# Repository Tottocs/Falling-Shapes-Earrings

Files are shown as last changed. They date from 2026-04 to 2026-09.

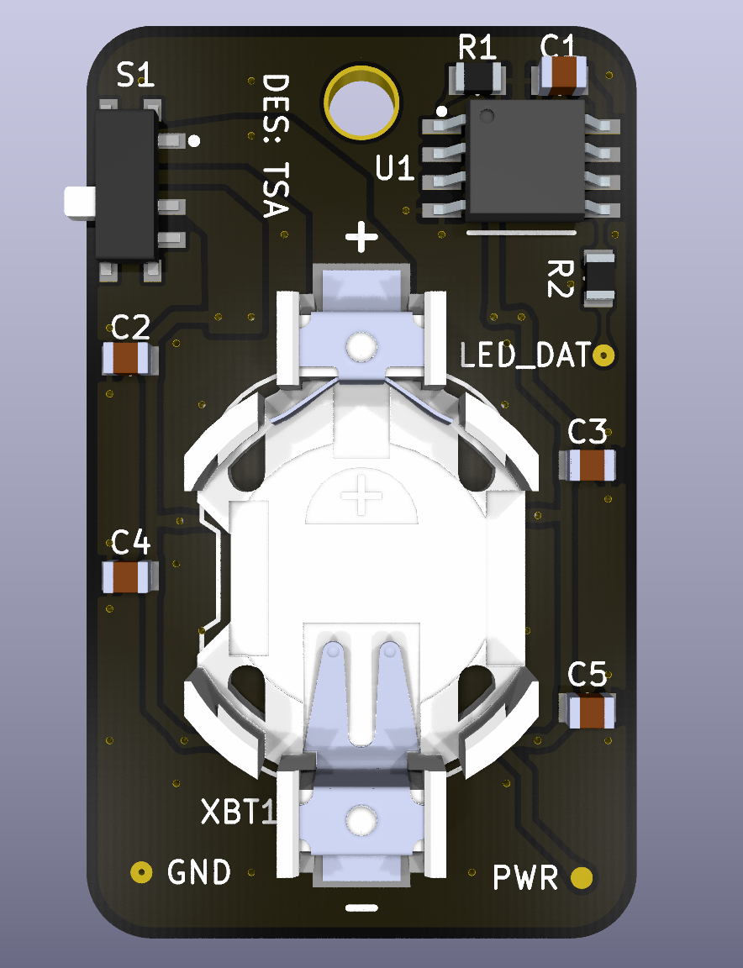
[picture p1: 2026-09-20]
pictures/renders/back.png

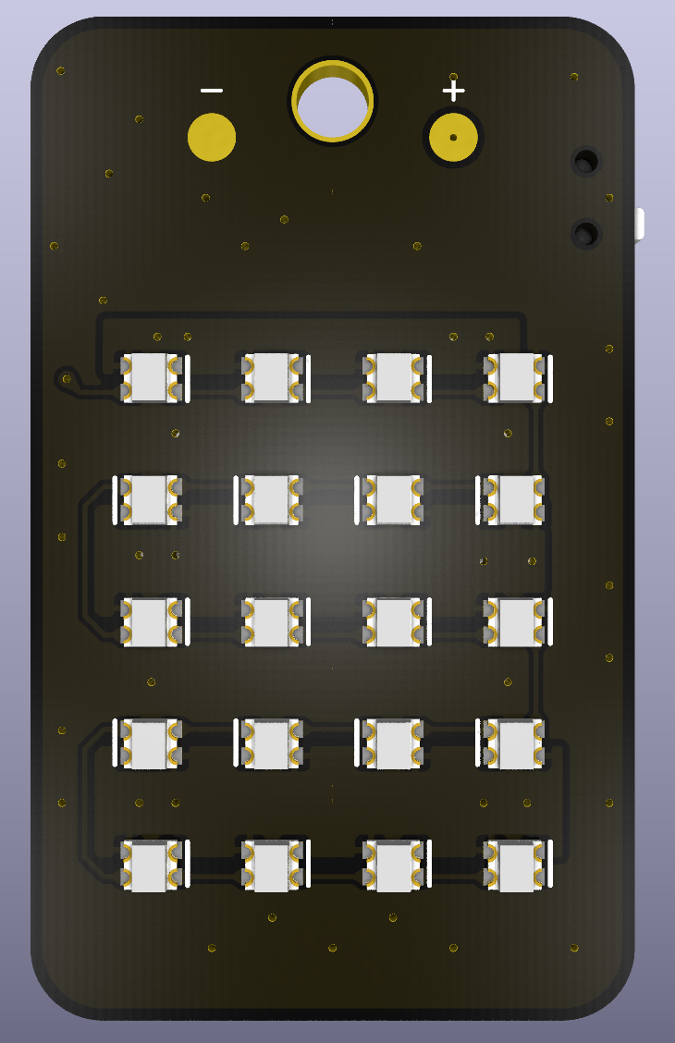
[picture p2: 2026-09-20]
pictures/renders/front.png

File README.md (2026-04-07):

# Falling Shapes Earrings
Earrings that display a falling shapes animation with an LED matrix. Made for my dear girlfriend. PCB designed in KiCad.

## License

This project is licensed under the Creative Commons Attribution-NonCommercial 4.0 International License (CC BY-NC 4.0).

Commercial use is not permitted.

See the LICENSE file for details.

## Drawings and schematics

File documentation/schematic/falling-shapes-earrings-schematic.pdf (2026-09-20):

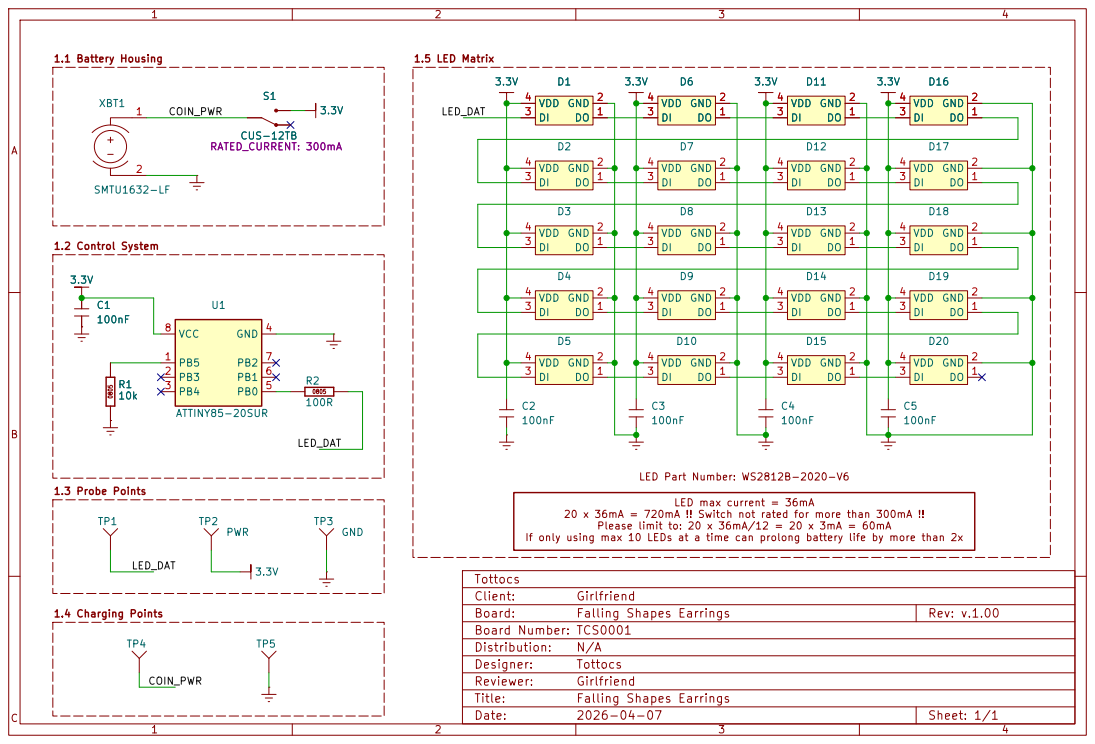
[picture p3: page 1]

LED max current = 36mA 20 x 36mA = 720mA !! Switch not rated for more than 300mA !! Please limit to: 20 x 36mA/12 = 20 x 3mA = 60mA

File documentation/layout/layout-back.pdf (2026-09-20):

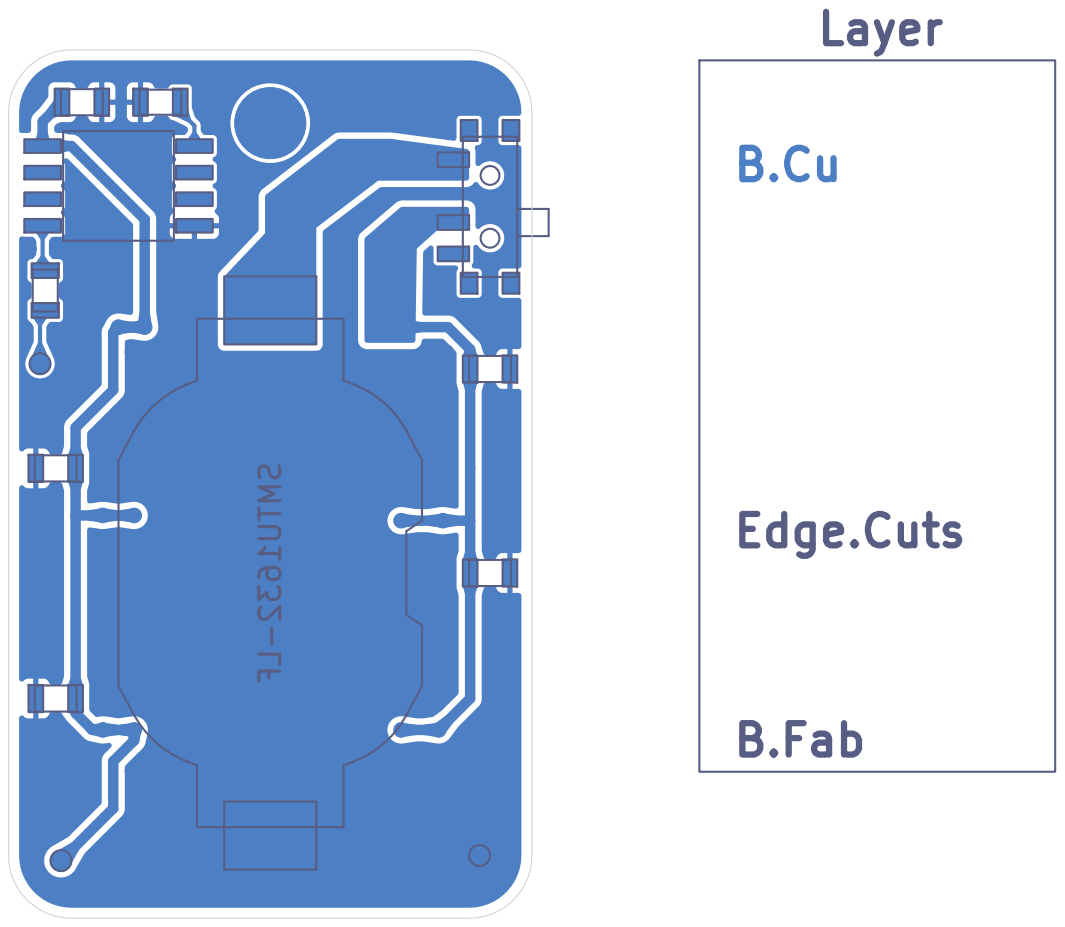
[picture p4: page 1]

TCS0001
Tottocs
Sheet:
File: falling-shapes-earrings.kicad_pcb
Title: Falling Shapes Earrings

Size: A5 | Rev: V1.0
KiCad E.D.A. 10.0.5 | Id: 1/4

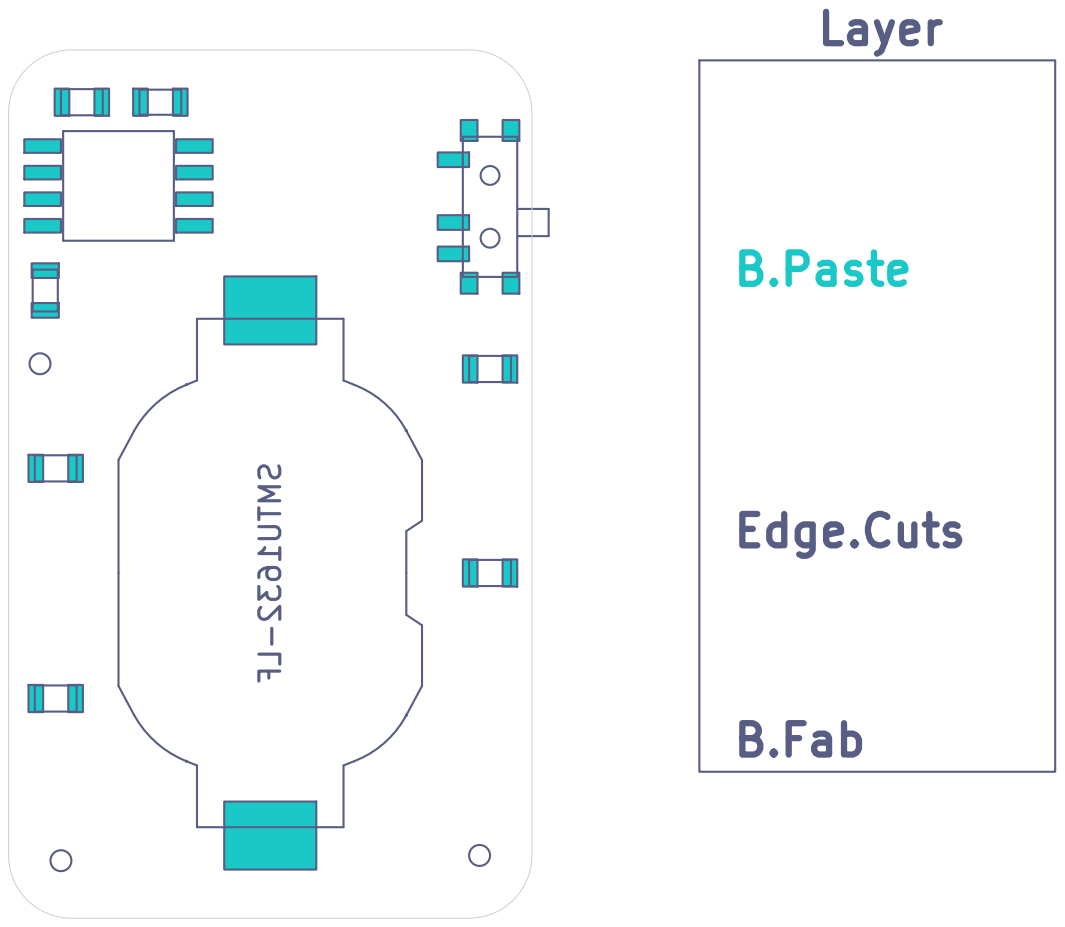
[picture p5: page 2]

TCS0001
Tottocs
Sheet:
File: falling-shapes-earrings.kicad_pcb
Title: Falling Shapes Earrings

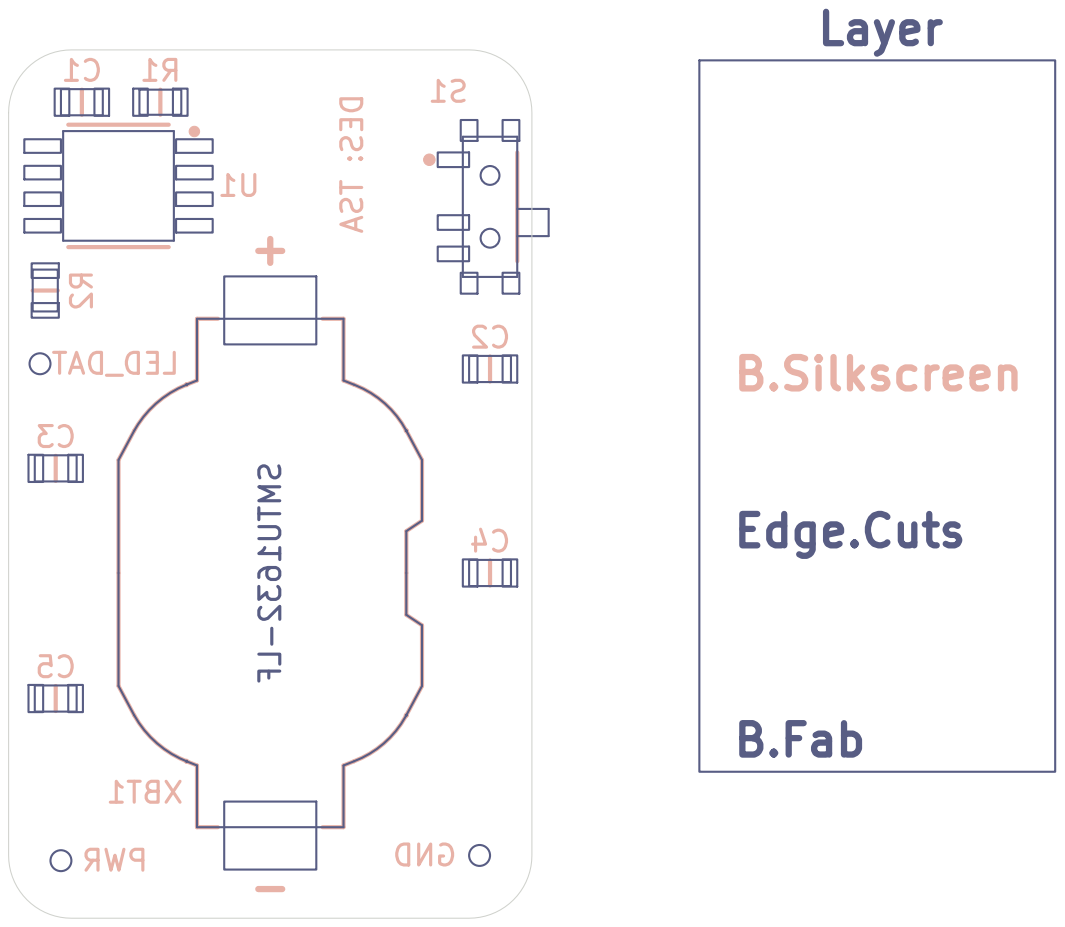
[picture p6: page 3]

Tottocs
Sheet:
File: falling-shapes-earrings.kicad_pcb
Title: Falling Shapes Earrings

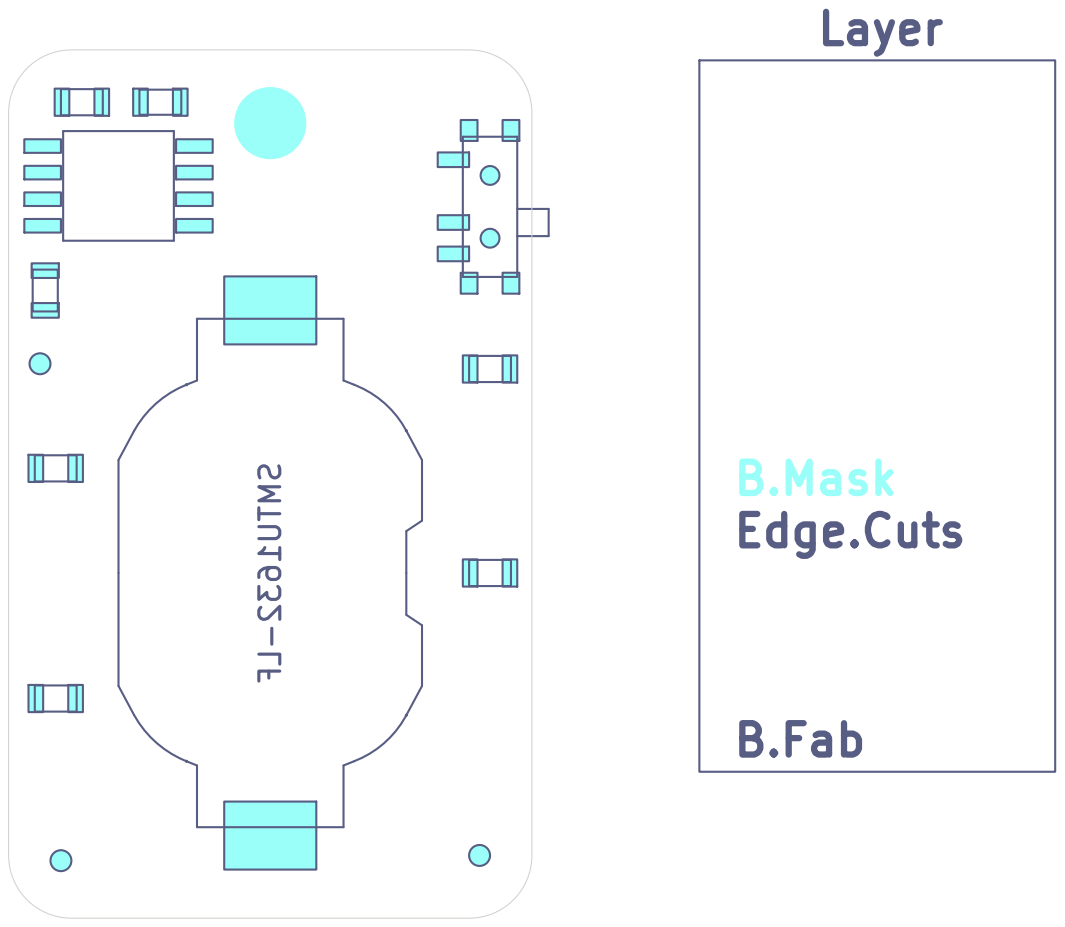
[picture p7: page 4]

TCS0001
Tottocs
Sheet:
File: falling-shapes-earrings.kicad_pcb
Title: Falling Shapes Earrings

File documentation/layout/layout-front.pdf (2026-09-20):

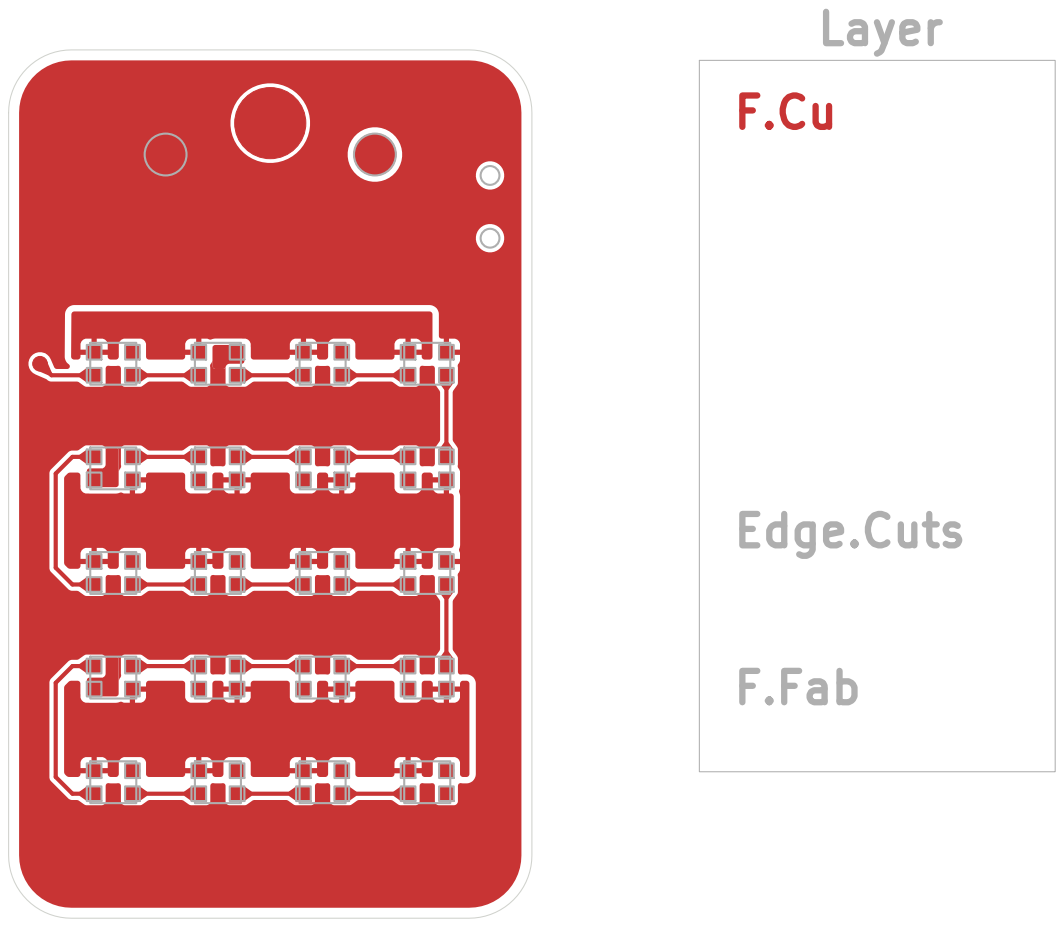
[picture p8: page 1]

TCS0001
Tottocs
Sheet:
File: falling-shapes-earrings.kicad_pcb
Title: Falling Shapes Earrings

Size: A5 | Rev: V1.0
KiCad E.D.A. 10.0.5 | Id: 1/4

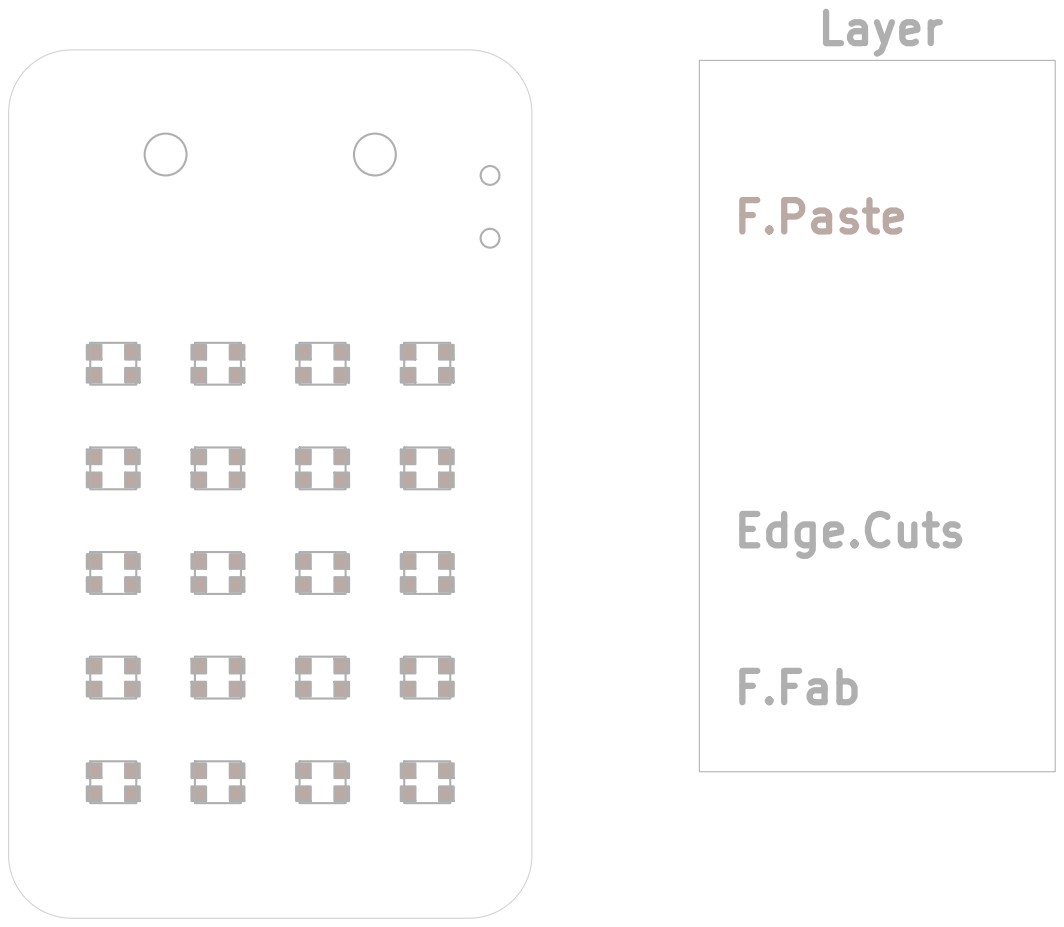
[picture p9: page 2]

TCS0001
Tottocs
Sheet:
File: falling-shapes-earrings.kicad_pcb
Title: Falling Shapes Earrings

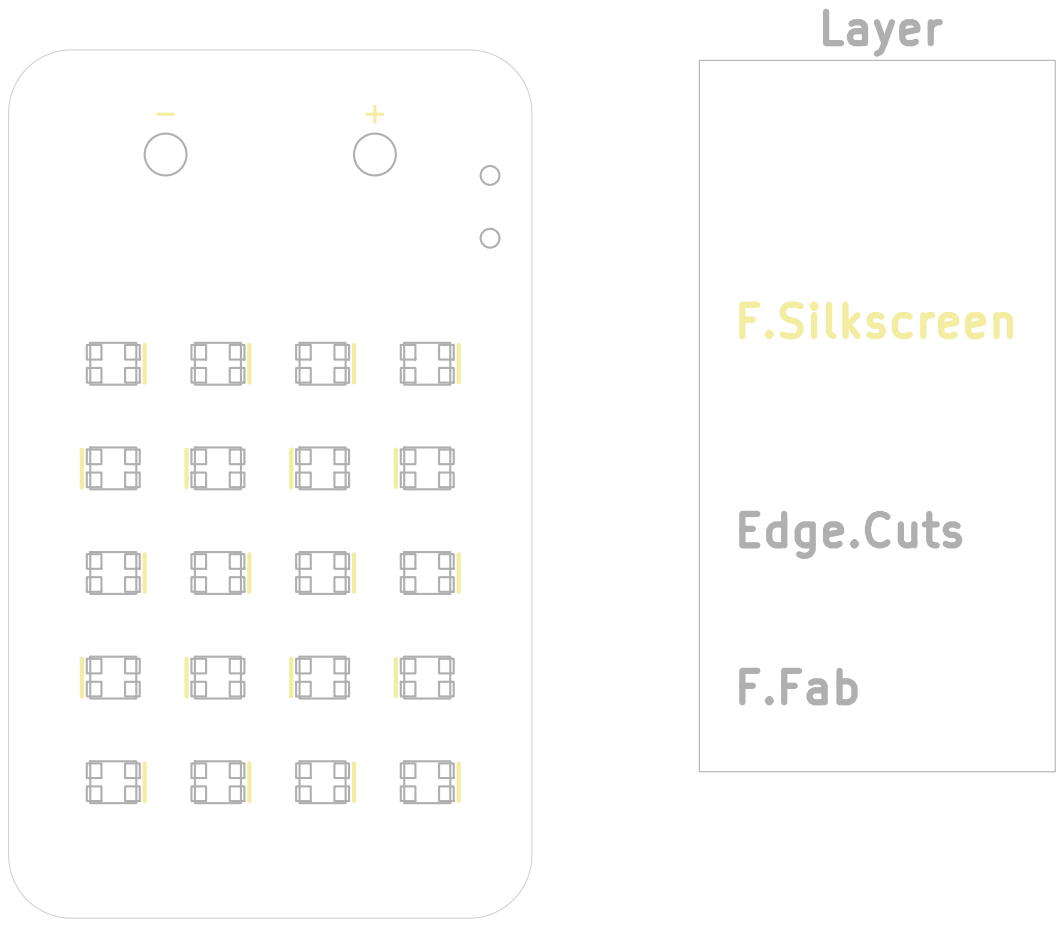
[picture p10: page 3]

TCS0001
Tottocs
Sheet:
File: falling-shapes-earrings.kicad_pcb
Title: Falling Shapes Earrings

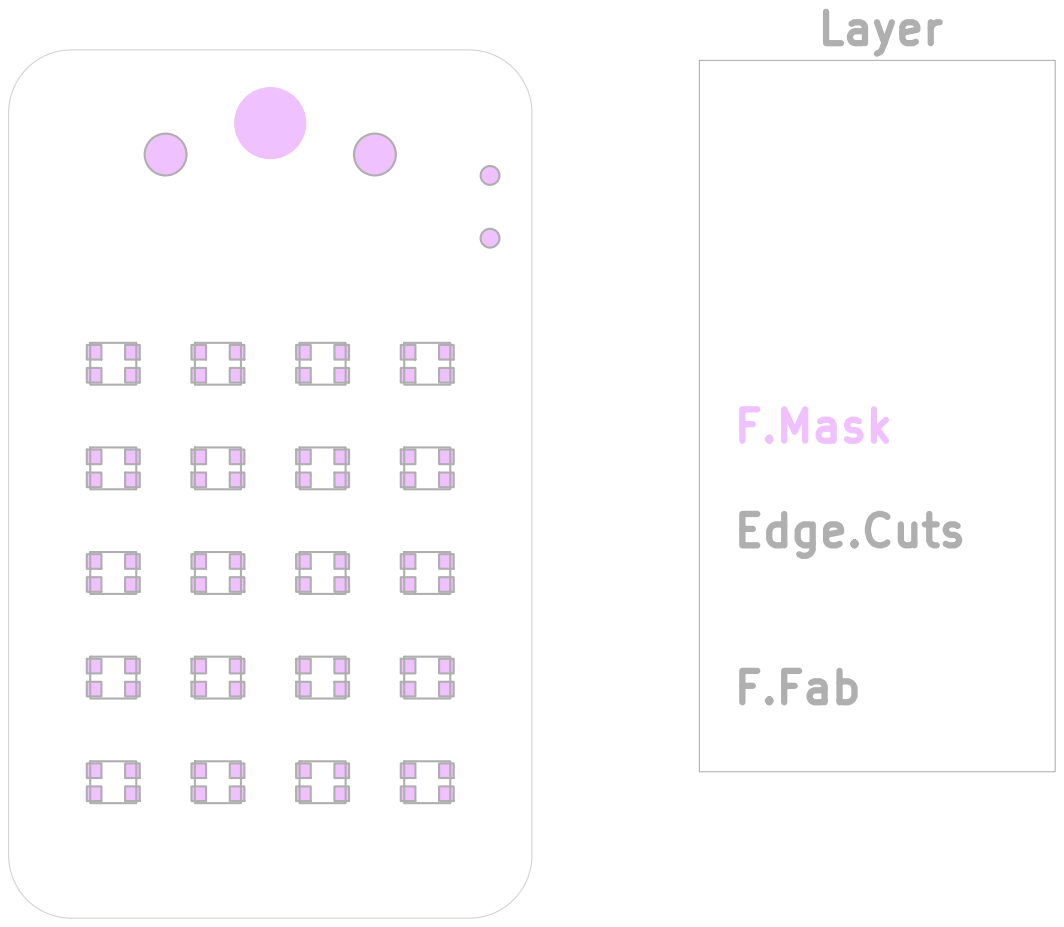
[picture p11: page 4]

TCS0001
Tottocs
Sheet:
File: falling-shapes-earrings.kicad_pcb
Title: Falling Shapes Earrings

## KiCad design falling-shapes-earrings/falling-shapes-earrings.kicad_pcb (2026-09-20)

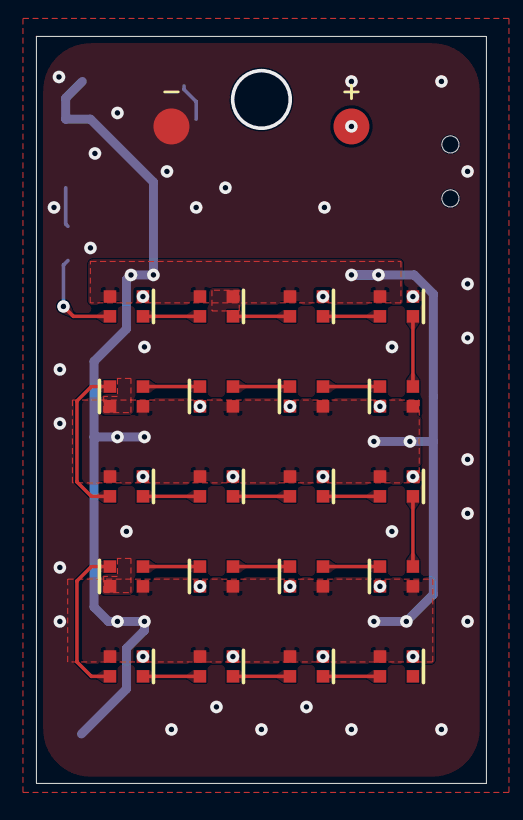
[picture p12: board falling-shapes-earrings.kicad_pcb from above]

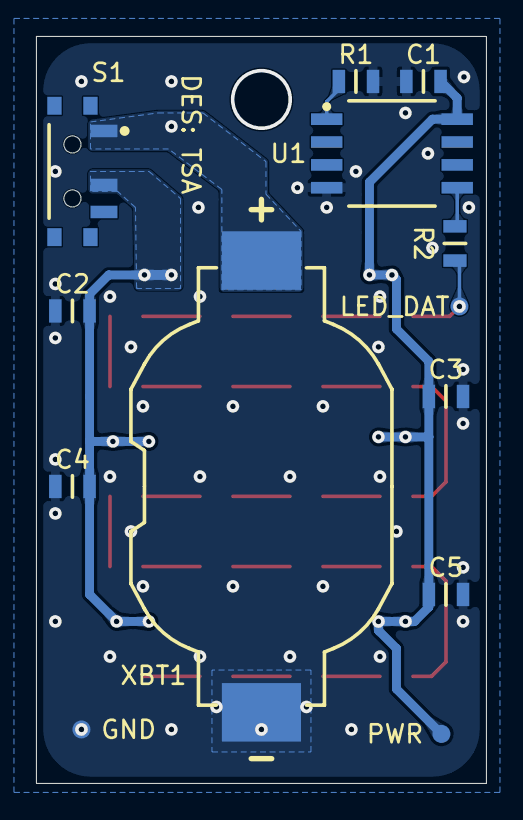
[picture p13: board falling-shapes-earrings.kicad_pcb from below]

Board: 2 copper layers, 25.0 x 41.5 mm, 35 parts (13 on the bottom side), 25 nets.

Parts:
C1, C2, C3, C4, C5: 100nF; C0805_0.25
D1, D2, D3, D4, D5, D6, D7, D8, D9, D10, D11, D12, D13, D14, D15, D16, D17, D18, D19, D20: WS2812B-2020-V6
R1: 10k; R0805_0_25
R2: 100R; R0805_0_25
S1: CUS-12TB; CUS12TB
TP1: LED_DAT; 1mm Test Pad
TP2: PWR; 1mm Test Pad
TP3: GND; 1mm Test Pad
TP4: +; 2mm Test Pad
TP5: -; 2mm Test Pad
U1: ATTINY85-20SUR; SOIC-8N (MS-012)
XBT1: SMTU1632-LF; SMTU1632LF

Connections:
3.3V: C1.2, C2.2, C3.2, C4.2, C5.2, D1.4 (VDD), D2.4 (VDD), D3.4 (VDD), D4.4 (VDD), D5.4 (VDD), D6.4 (VDD), D7.4 (VDD), D8.4 (VDD), D9.4 (VDD), D10.4 (VDD), D11.4 (VDD), D12.4 (VDD), D13.4 (VDD), D14.4 (VDD), D15.4 (VDD), D16.4 (VDD), D17.4 (VDD), D18.4 (VDD), D19.4 (VDD), D20.4 (VDD), S1.2, TP2.1 (Test_1), U1.8 (VCC)
/COIN_PWR: S1.1, TP4.1 (Test_1), XBT1.1
/LED_DAT: D1.3 (DI), R2.2, TP1.1 (Test_1)
GNDREF: C1.1, C2.1, C3.1, C4.1, C5.1, D1.2 (GND), D2.2 (GND), D3.2 (GND), D4.2 (GND), D5.2 (GND), D6.2 (GND), D7.2 (GND), D8.2 (GND), D9.2 (GND), D10.2 (GND), D11.2 (GND), D12.2 (GND), D13.2 (GND), D14.2 (GND), D15.2 (GND), D16.2 (GND), D17.2 (GND), D18.2 (GND), D19.2 (GND), D20.2 (GND), R1.1, TP3.1 (Test_1), TP5.1 (Test_1), U1.4 (GND), XBT1.2
unnamed: D1.1 (DO), D6.3 (DI)
unnamed: D2.1 (DO), D7.3 (DI)
unnamed: D3.1 (DO), D8.3 (DI)
unnamed: D4.1 (DO), D9.3 (DI)
unnamed: D5.1 (DO), D10.3 (DI)
unnamed: D10.1 (DO), D15.3 (DI)
unnamed: D6.1 (DO), D11.3 (DI)
unnamed: D11.1 (DO), D16.3 (DI)
unnamed: D7.1 (DO), D12.3 (DI)
unnamed: D12.1 (DO), D17.3 (DI)
unnamed: D8.1 (DO), D13.3 (DI)
unnamed: D13.1 (DO), D18.3 (DI)
unnamed: D9.1 (DO), D14.3 (DI)
unnamed: D14.1 (DO), D19.3 (DI)
unnamed: D15.1 (DO), D20.3 (DI)
unnamed: D2.3 (DI), D16.1 (DO)
unnamed: D3.3 (DI), D17.1 (DO)
unnamed: D4.3 (DI), D18.1 (DO)
unnamed: D5.3 (DI), D19.1 (DO)
unnamed: R2.1, U1.5 (PB0)
unnamed: R1.2, U1.1 (PB5)

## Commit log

2026-04-07 Added KiCad Project
    [falling-shapes-earrings.kicad_pcb, falling-shapes-earrings.kicad_sch]
2026-08-03 Update falling-shapes-earrings.kicad_pro
    Project update
2026-08-05 Update falling-shapes-earrings.kicad_pro
    Minor change
2026-08-08 Update falling-shapes-earrings.kicad_sch
    Added symbols to schematic
    [falling-shapes-earrings.kicad_sch]
2026-08-08 Update falling-shapes-earrings.kicad_sch
    Adding power symbols
    [falling-shapes-earrings.kicad_sch]
2026-08-11 Update falling-shapes-earrings.kicad_sch
    Annotation changes and capacitor changes
    [falling-shapes-earrings.kicad_sch]
2026-08-13 Update falling-shapes-earrings.kicad_sch
    Added switch and made minor changes to battery housing
    [falling-shapes-earrings.kicad_sch]
2026-08-13 Updated Revision to V0.03
    [falling-shapes-earrings.kicad_sch]
2026-08-13 Update falling-shapes-earrings.kicad_sch
    V0.1: Initial finished drawing
    [falling-shapes-earrings.kicad_sch]
2026-08-13 Update falling-shapes-earrings.kicad_sch
    V0.1
    [falling-shapes-earrings.kicad_sch]
2026-08-13 Update falling-shapes-earrings.kicad_pro
    V0.1 minor change
2026-08-17 Update falling-shapes-earrings.kicad_sch
    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
    [falling-shapes-earrings.kicad_sch]
2026-08-19 Update falling-shapes-earrings.kicad_sch
    V0.2: Added footprints for all current parts, added programming header section
    [falling-shapes-earrings.kicad_sch]
2026-08-19 Update falling-shapes-earrings.kicad_pro
    Changed revision
2026-08-23 Update falling-shapes-earrings.kicad_sch
    Ran an ERC and corrected errors
    [falling-shapes-earrings.kicad_sch]
2026-08-23 Update falling-shapes-earrings.kicad_pcb
    Made first draft of layout
    [falling-shapes-earrings.kicad_pcb]
2026-08-23 Update falling-shapes-earrings.kicad_pro
    Minor changes
2026-08-27 Create falling-shapes-earrings.kicad_dru
    Design Rules
2026-08-27 Update falling-shapes-earrings.kicad_pcb
    Ran design rule without violation
    [falling-shapes-earrings.kicad_pcb]
2026-08-27 Update falling-shapes-earrings.kicad_sch
    V0.90 Added charge points and updated symbols from libraries
    [falling-shapes-earrings.kicad_sch]
2026-09-20 Created Gerbers
    [falling-shapes-earrings-B_Cu.gbl, falling-shapes-earrings-B_Mask.gbs, falling-shapes-earrings-B_Paste.gbp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]
2026-09-20 Update falling-shapes-earrings.kicad_pcb
    Finilised PCB and ran drc (clean)
    [falling-shapes-earrings.kicad_pcb]
2026-09-20 Update falling-shapes-earrings.kicad_pro
    Added bom present and changed project to v1.00
2026-09-20 Update falling-shapes-earrings.kicad_sch
    Changed to v1.00
    [falling-shapes-earrings.kicad_sch]
